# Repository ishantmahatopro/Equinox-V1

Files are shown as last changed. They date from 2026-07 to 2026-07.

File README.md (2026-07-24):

# Equinox V1

Equinox V1 is my custom full size (108 key) wireless mechanical keybaord, its built around a **Adafruit Feather nRF52840 Express**.

so basicaly i wanted a full size board that could go fully wireles over bluetooth but still work as a normal wired keyboard when i need it too, and i really didnt want to just buy some kit and screw it togther.. i wanted to actualy understand how the whole thing works like the matrix the diodes the I2C gpio expanders the battery the little screen ALL of it, so i designed the entire thing from scratch in kicad and fusion 360 which took forever lol

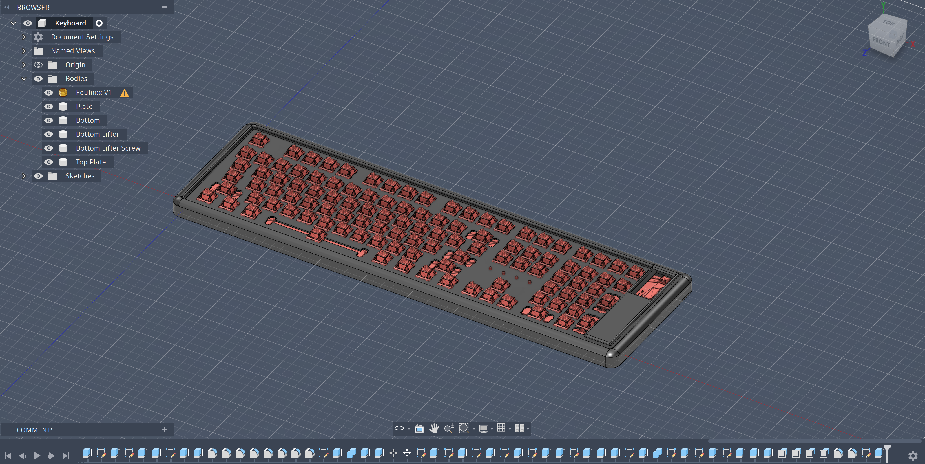
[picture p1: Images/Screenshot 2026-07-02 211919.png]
Equinox V1 full 3D model


## why i made this

im 17 and i basicaly live on my keyboard, school work,coding, everything.. so i figured if im gonna be typing on somthing like 8 hours a day it might aswell be somthing i built myself and actualy understand top to bottom right

main goals i set for myself :

- design a full size PCB in kicad (108 keys, numpad + nav cluster included)
- make it **wireless** (BLE) off a lipo battery,, but keep usb-c as a backup incase
- drive a huge key matrix off only 2 I2C pins using the MCP23017 expanders
- add a little 1.9" LCD that runs a animated cherry blossom scene, just becuase i thought it looked cool
- keep the whole thing actualy manufacturable (real production files not just a pretty render)
- learn the full pipline : schematic -> pcb -> 3d model -> printed case -> firmware

honestly the wireless part was the scaryest bit and it took me alot of trys to get the matrix scaning right over the expanders,, but it works now so im happy

## project status

this repo has the complete hardware design + manufacturing outputs. its basicaly done as a "V1", theres definately stuff i would change for a V2 but everything here is real and usable

whats included :

- kicad project, schematic and pcb
- full 3d cad (fusion 360 + `.step` export)
- printable case parts (`.stl`) and a plate dxf
- production files (bom, positions, designators, ipc netlist, gerber zip)
- kmk firmware for the nrf52840

current hardware summary :

| | |
|---|---|
| Layout | full size, 108 keys (main block + nav + numpad) |
| Controller | Adafruit Feather nRF52840 Express |
| Connectivity | bluetooth LE **and** usb-c (Fn+Esc toggles at runtime) |
| Matrix | 21 columns x 6 rows, scaned through 2x MCP23017 I2C expanders |
| Diodes | 1N4148W, one per switch (COL2ROW) |
| Battery | 500mAh 1S lipo, with charge / low battery status leds |
| Display | Waveshare 1.9" ST7789 IPS lcd (animated cherry blossom scene) |
| Stabilizers | Durock Clear screw-in V2 (6.25u space + 2u / 2.25u / 2.75u) |
| Switches | Akko V3 Penguin Pro |
| Keycaps | Plum Blossom cherry profile shine-through PBT |
| Case | 3d printed (Hack Club PrintLegion) |
| PCB | fabbed at JLCPCB |

the keycaps are pink plum blossom shine through and the lcd runs a pink cherry blossom animation so the whole "Equinox" theme kinda just came togther around that,, wasnt even fully planned tbh

## images

### full 3d model
Assembled 3D model with switches

### indicator leds (caps / num / charging)
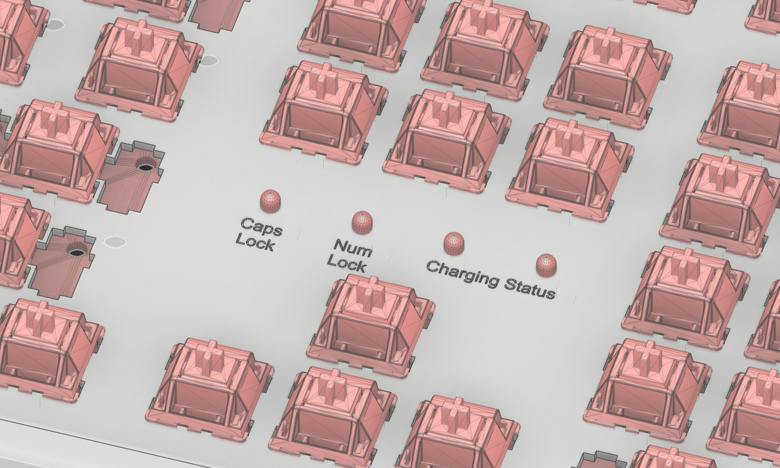
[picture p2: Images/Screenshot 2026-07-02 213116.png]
Close up of the status LED indicators


### pcb
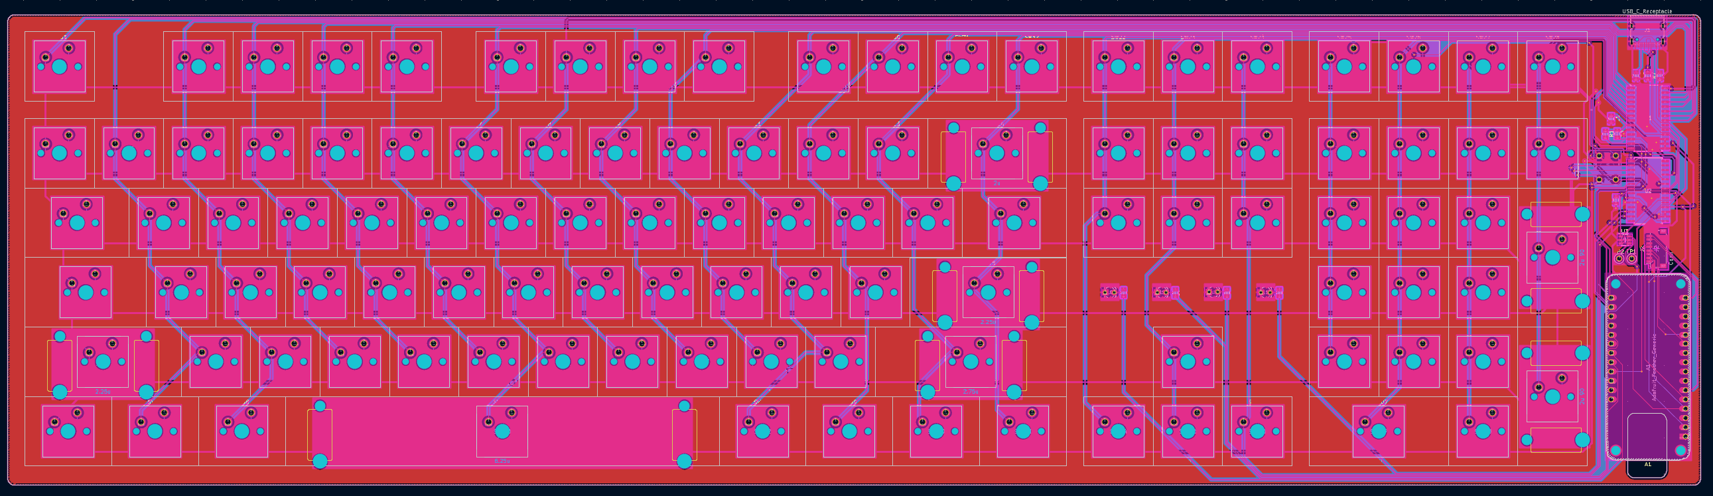
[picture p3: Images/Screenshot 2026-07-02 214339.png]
Equinox V1 PCB routing


### schematic / wiring
the matrix, both gpio expanders, the mcu, usb-c, esd protection, stabs and display are all on one sheet..

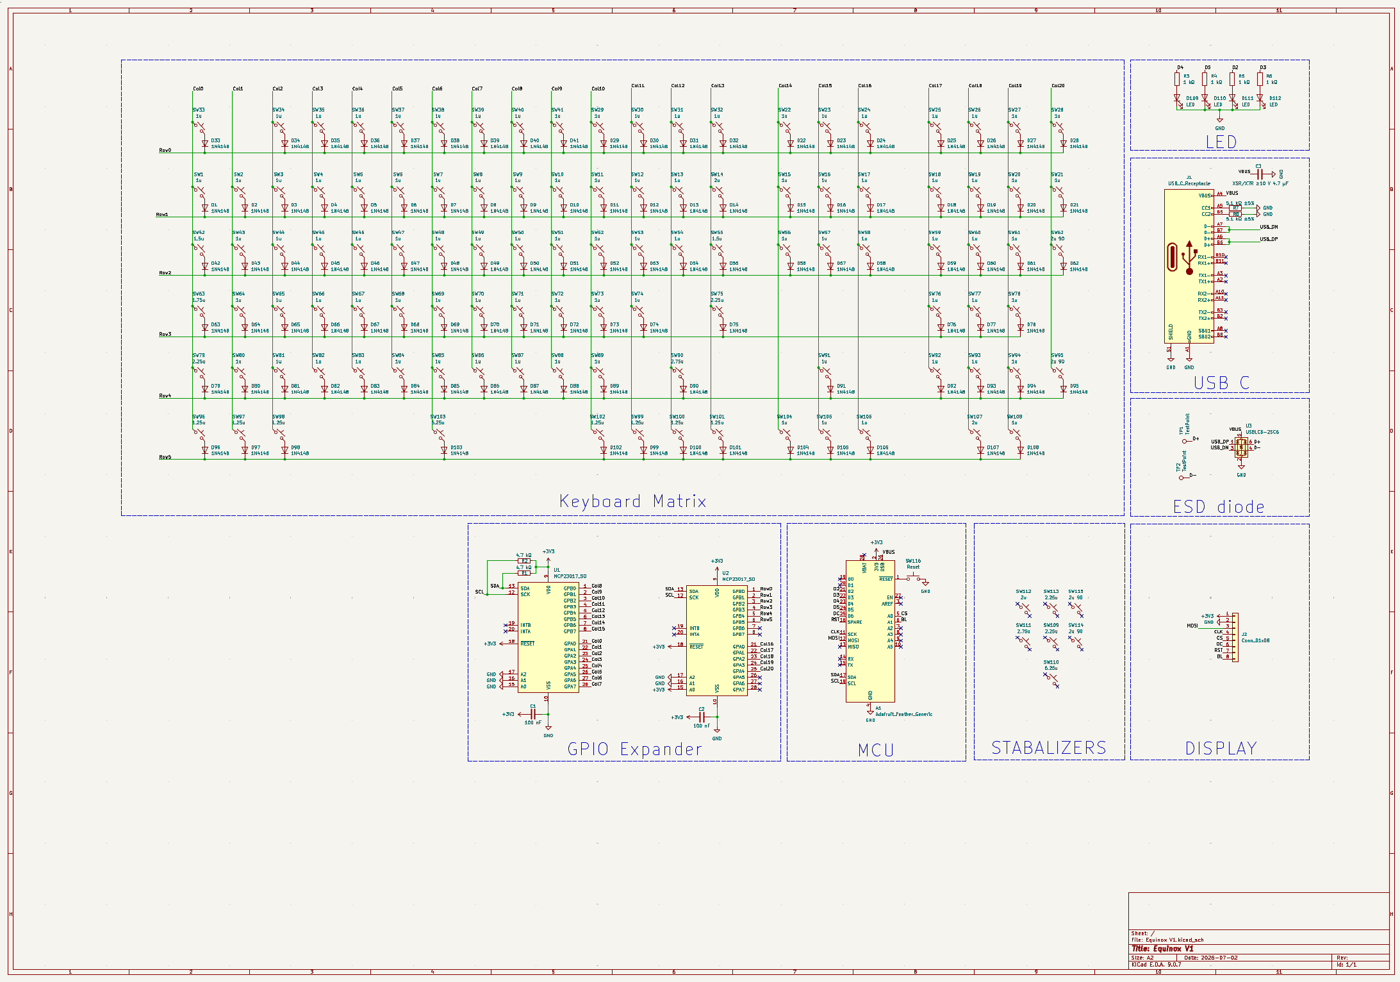
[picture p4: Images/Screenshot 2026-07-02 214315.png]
Equinox V1 schematic


### other screenshots
some more views of the case and plate from fusion

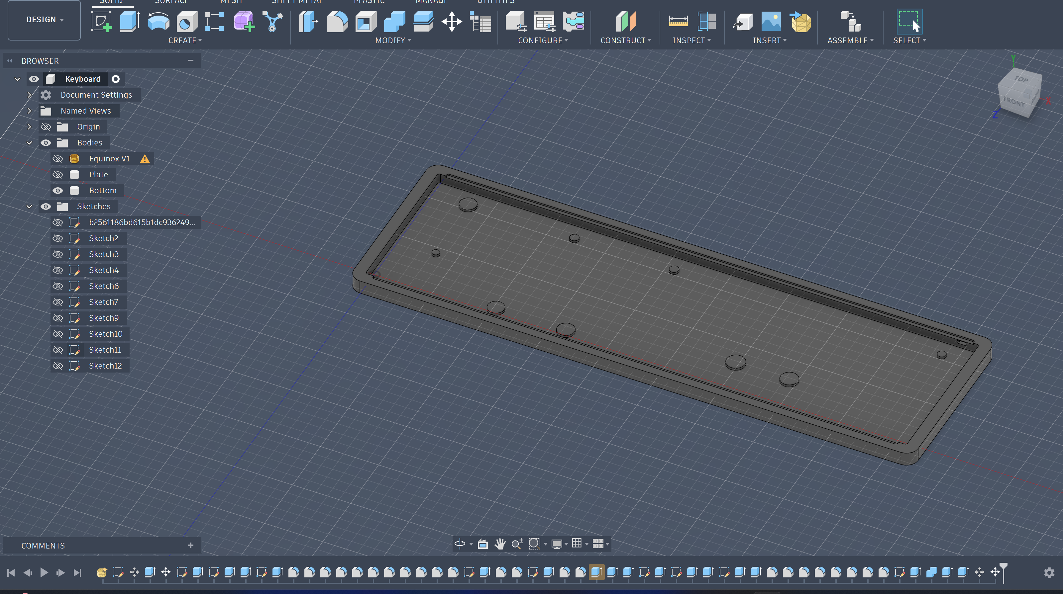
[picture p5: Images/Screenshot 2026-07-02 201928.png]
Case tray

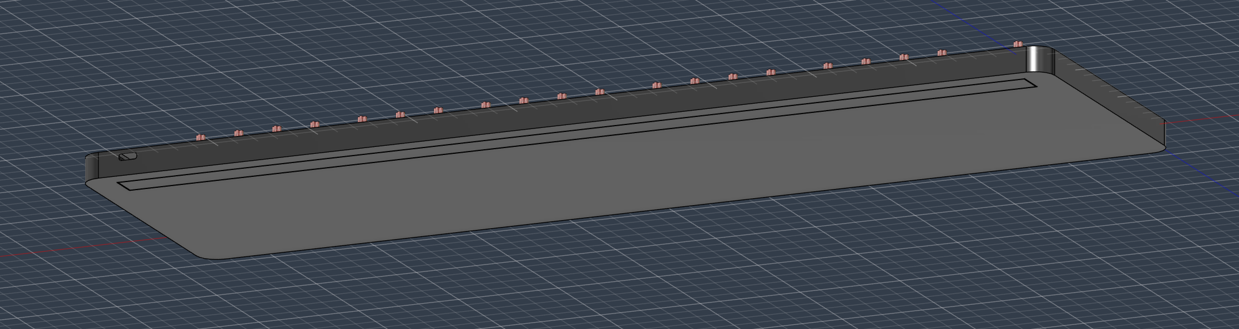
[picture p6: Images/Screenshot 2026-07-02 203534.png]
Case side profile

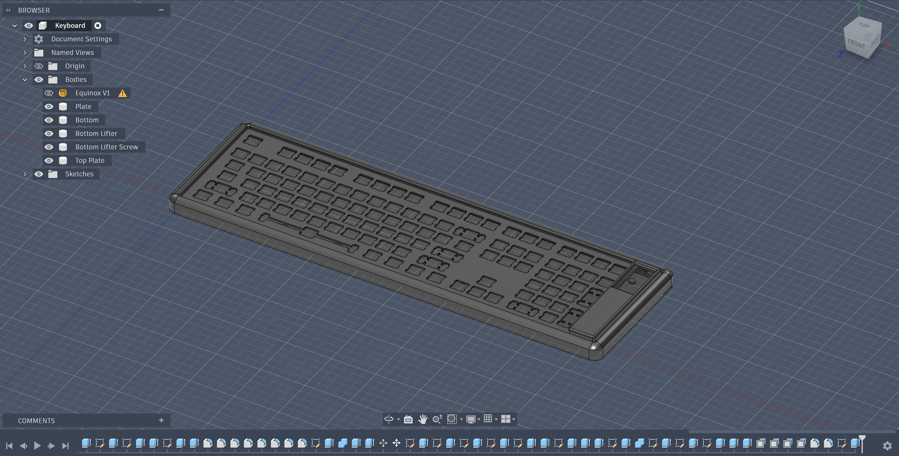
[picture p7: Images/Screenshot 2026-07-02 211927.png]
Switch plate cutouts

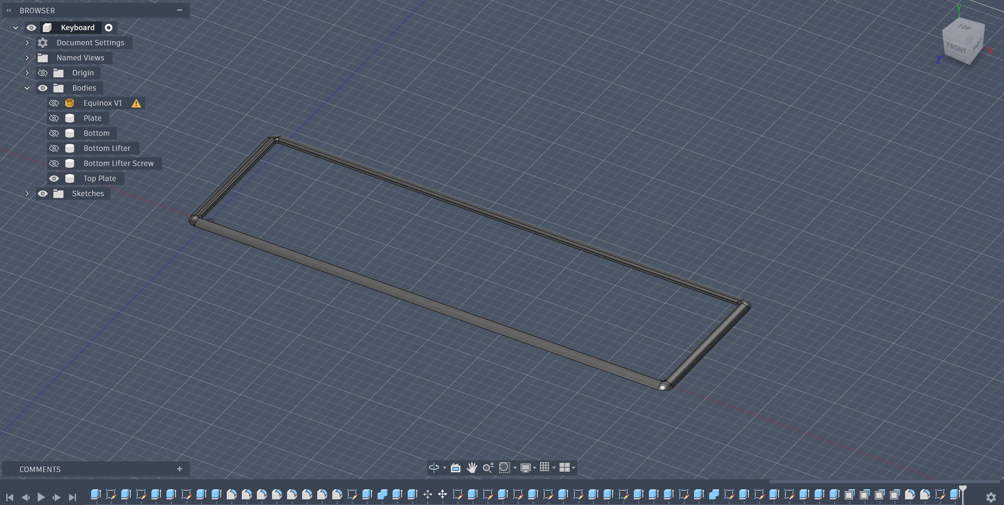
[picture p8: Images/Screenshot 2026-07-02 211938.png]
Top plate frame

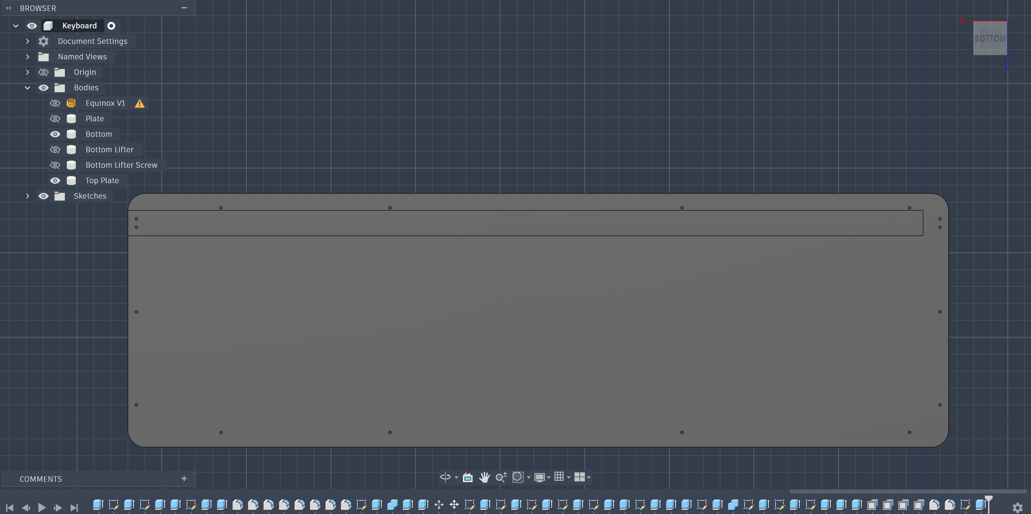
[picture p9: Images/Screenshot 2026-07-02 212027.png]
Bottom case


## repo file checklist

important files in this repo :

- `PCB/Equinox V1.kicad_pro`
- `PCB/Equinox V1.kicad_sch`
- `PCB/Equinox V1.kicad_pcb`
- `CAD/Full Equinox V1/Equinox V1.step`
- `CAD/Printing Files/`  -> `Plate.stl`, `Top Plate.stl`, `Bottom.stl`, `Bottom Lifter.stl`, `Bottom Lifter Screw.stl`
- `Firmware/code.py`
- `Production/bom.csv`
- `Production/positions.csv`
- `Production/designators.csv`
- `Production/netlist.ipc`
- `Production/Equinox_V1.zip`  (gerbers)
- `bom.csv`
- `PDFs/Equinox V1.pdf`  (schematic print)

## cad

designed in **fusion 360**.. theres a `.step` export right next to it if you just want the geometry. all the print ready parts are in `CAD/Printing Files/`

## firmware note

firmware is **KMK** running on **circuitpython**, its all in one file :

- `Firmware/code.py`

it has the real nrf52840 feather pin map, both MCP23017 adresses (`0x20` and `0x21`), the full 108 key layout maped from my layout photo, the lock/battery led logic and the cherry blossom lcd animation. all the periferal code is wraped in try/except so if a display or a led pin is wrong it still lets you type it just skips that part

to flash it : double tap RESET on the feather, drop the circuitpython `.uf2`, then copy `code.py` plus the `kmk/` folder and the required `lib/` drivers (`adafruit_mcp230xx`, `adafruit_bus_device`, `adafruit_ble`, `adafruit_st7789`, `adafruit_display_text`) onto the `CIRCUITPY` drive

by defalt it boots as **usb** (easyest for first bring up) and **Fn+Esc** switches over to bluetooth. if you want it wireless first just swap `hid_type` and `secondary_hid_type` at the bottom of `code.py`

## bom (summary)

full bom is in `bom.csv`. prices are what i actualy payed (usd)

| # | Name | Purpose | Qty | Cost ($) | Distributor | Link |
|---|---|---|-----|---|---|---|
| 1 | 3D printed Case | keyboard case | 1 | 8 | Hack Club | [Buy](https://printlegion.hackclub.com) |
| 2 | PCB fabrication | the main board | 1 | 39.36 | JLCPCB | [Buy](https://cart.jlcpcb.com/shopcart/cart) |
| 3 | Plum Blossom Cherry Profile Top Shine-Through PBT Keycap Set V2 | keycaps to actualy type on | 1 | 28.35 | Curiosity Caps | [Buy](https://curiositycaps.in/products/plum-blossom-cherry-profile-shine-through-dye-sublimation-pbt-keycap-set) |
| 4 | Durock Clear Screw-In Stabilizers V2 | stabalizers to keep the big keys stable | 1 | 24.83 | Stackskb | [Buy](https://stackskb.com/store/durock-clear-screw-in-stabilizers-v2/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) |
| 5 | Akko V3 Penguin Pro Switch (Pack of 45) | switches for the keys | 3(Already Have) | 47.22 | Stackskb | [Buy](https://stackskb.com/store/akko-penguin-pro-switch-pack-of-45/) |
| 6 | Adafruit Feather nRF52840 Express | microcontroler / the brains | 1 | 32.02 | Robu | [Buy](https://robu.in/product/adafruit-feather-nrf52840-express/) |
| 7 | WLY752530 3.7V 500mAh 1S LiPo Battery | battery | 1 | 2.74 | Robu | [Buy](https://robu.in/product/500mah-pcm-protected-micro-li-po-battery/) |
| 8 | 0805 X7R 100nF 50V ceramic capacitors | capacitors | 10 | 0.12 | Robu | [Buy](https://robu.in/product/tcc0805x7r104j500dt-cctc-smt-ceramic-capacitors-0805-x7r-104j100nf%c2%b15-0-rated-voltage50v-thickness0-85mmtape/) |
| 9 | Samsung 4.7uF 10V X7R 0805 capacitors | capacitors | 5 | 0.12 | Robu | [Buy](https://robu.in/product/cl21b475kpqvpne-samsung-cap-ceramic-4-7uf-10v-x7r-10-pad-smd-0805-125c-t-r-automotive-aec-q200/) |
| 10 | 1N4148W SOD-123 Diode | diode (1 per switch) | 216 | 1.59 | Robu | [Buy](https://robu.in/product/1n4148w-sod-123-1206-diodereel-of-3000/) |
| 11 | 3mm Green DIP LED | led | 15 | 0.12 | Robu | [Buy](https://robu.in/product/3mm-green-dip-led-pack-of-50/) |
| 12 | 3mm Red DIP LED | led | 15 | 0.14 | Robu | [Buy](https://robu.in/product/3mm-red-dip-led-pack-of-50/) |
| 13 | 16P Female Type-C SMD Connector | usb-c port | 2 | 0.8 | Robu | [Buy](https://robu.in/product/type-c-31-m-12-hroparts-5a-1-16p-female-type-c-smd-usb-connectors-rohs/) |
| 14 | XY308-2.54 3 Pin Screw Terminal Block | battery terminal | — | Free | Robu | — |
| 15 | JST SH 1x8P Right Angle Connector | display conection | 2 | 1.09 | Robu | [Buy](https://robu.in/product/sm08b-srss-tblfsn-jst-1x8p-8p-sh-tin-8-25%e2%84%8385%e2%84%83-1a-1-1mm-copper-alloy-surface-mount-smdp1mmsurface-mount%ef%bc%8cright-angle-wi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) |
| 16 | Panasonic 4.7 kohm 0805 resistor | resistors (i2c pullups) | 11 | 0.11 | Robu | [Buy](https://robu.in/product/erj6enf4701v-panasonic-smd-chip-resistor-4-7-kohm-%c2%b1-1-125-mw-0805-2012-metric-thick-film-precision/) |
| 17 | Vishay 1 kohm 0805 resistor | resistors (led current limit) | 20 | 0.72 | Robu | [Buy](https://robu.in/product/crcw08051k00fkeahp-vishay-smd-chip-resistor-1-kohm-%c2%b1-1-500-mw-0805-2012-metric-thick-film-pulse-proof-high-power/) |
| 18 | Yageo 5.1 kohm 0805 resistor | resistors | 100 | 0.14 | Robu | [Buy](https://robu.in/product/rc0805jr-075k1l-yageo-smd-chip-resistor-5-1-kohm-%c2%b1-5-125-mw-0805-2012-metric-thick-film-general-purpose/) |
| 19 | MCP23017-E/SO I/O Expander (16-bit, I2C) | gpio expander | 4 | 8.78 | Robu | [Buy](https://robu.in/product/mcp23017-e-so-microchip-i-o-expander-16-bit-i2c-serial-1-8-v-5-5-v-soic-28-pins/) |
| 20 | USBLC6-2SC6 SOT-23-6 | esd / surge protection | 5 | 0.37 | Robu | [Buy](https://robu.in/product/usblc6-2sc6-ms-msksemi-4-5a-15v-150w-6v-5v-sot-23-6-esd-and-surge-protection-tvs-esd-rohs/) |
| 21 | Waveshare 1.9inch LCD Display Module (SPI, IPS) | the screen | 1 | 11.17 | Robu | [Buy](https://robu.in/product/waveshare-lcd-display-module-spi-interface-262k-colors/) |

**total bom cost : $160**

---

thanks for reading,, if you build one or have any questions feel free to open a issue. this was my first proper wireless board so its deffinately not perfect but i learnt a insane amount making it :)

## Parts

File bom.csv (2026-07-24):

Name | Purpose | Quantity | Total Cost ($) | Link | Distributor
3D printed Case | Keyboard Case | 1 | 8 | https://printlegion.hackclub.com | Hack Club
PCB fabrication | Keyboard Main Board | 1 | 39.36 | https://cart.jlcpcb.com/shopcart/cart | JLCPCB
Plum Blossom Cherry Profile Top Shine-Through PBT Keycap Set V2 | KeyCaps for the Keyboard to type | 1 | 28.35 | https://curiositycaps.in/products/plum-blossom-cherry-profile-shine-through-dye-sublimation-pbt-keycap-set | Curiosity Caps
Durock Clear Screw-In Stabilizers V2 | Stabalizers to keep Big keys stable | 1 | 24.83 | https://stackskb.com/store/durock-clear-screw-in-stabilizers-v2/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 | Stackskb
Akko V3 Penguin Pro Switch (Pack of 45) | Switches for the Keys | 3 | 47.22 | https://stackskb.com/store/akko-penguin-pro-switch-pack-of-45/ | Stackskb
Adafruit Feather nRF52840 Express | Microcontroller | 1 | 32.02 | https://robu.in/product/adafruit-feather-nrf52840-express/ | Robu
WLY752530 3.7V 500mAh 1S LiPo Battery – Micro Rechargeable Battery Pack for Wearables / Micro Drone / IoT | Battery | 1 | 2.74 | https://robu.in/product/500mah-pcm-protected-micro-li-po-battery/ | Robu
TCC0805X7R104J500DT-CCTC-SMT ceramic capacitors 0805 X7R 104J(100nF)±5.0% Rated voltage:50V thickness:0.85mmtape | Capacitors | 10 | 0.12 | https://robu.in/product/tcc0805x7r104j500dt-cctc-smt-ceramic-capacitors-0805-x7r-104j100nf%c2%b15-0-rated-voltage50v-thickness0-85mmtape/ | Robu
CL21B475KPQVPNE-Samsung-Cap Ceramic 4.7uF 10V X7R 10% Pad SMD 0805 125°C T/R Automotive AEC-Q200 | Capacitors | 5 | 0.12 | https://robu.in/product/cl21b475kpqvpne-samsung-cap-ceramic-4-7uf-10v-x7r-10-pad-smd-0805-125c-t-r-automotive-aec-q200/ | Robu
1N4148W SOD-123 1206 Diode | Diode | 216 | 1.59 | https://robu.in/product/1n4148w-sod-123-1206-diodereel-of-3000/ | Robu
3mm Green DIP LED | Led | 15 | 0.12 | https://robu.in/product/3mm-green-dip-led-pack-of-50/ | Robu
3mm Red DIP LED | Led | 15 | 0.14 | https://robu.in/product/3mm-red-dip-led-pack-of-50/ | Robu
TYPE-C-31-M-12-Hroparts-5A 1 16P Female Type-C SMD USB Connectors ROHS | Type C | 2 | 0.8 | https://robu.in/product/type-c-31-m-12-hroparts-5a-1-16p-female-type-c-smd-usb-connectors-rohs/ | Robu
XY308-2.54-XINYA-3 Pin Screw Terminal Block(Red) | Free |  |  |  | Robu
SM08B-SRSS-TB(LF)(SN)-JST-1x8P 8P SH Tin 8 -25?~+85? 1A 1 1mm Copper alloy Surface Mount SMD,P=1mm,Surface Mount?Right Angle Wire To Board Connector ROHS | OLED Connection | 2 | 1.09 | https://robu.in/product/sm08b-srss-tblfsn-jst-1x8p-8p-sh-tin-8-25%e2%84%8385%e2%84%83-1a-1-1mm-copper-alloy-surface-mount-smdp1mmsurface-mount%ef%bc%8cright-a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 | Robu
ERJ6ENF4701V-PANASONIC-SMD Chip Resistor, 4.7 kohm, ± 1%, 125 mW, 0805 [2012 Metric], Thick Film, Precision | Resistors | 11 | 0.11 | https://robu.in/product/erj6enf4701v-panasonic-smd-chip-resistor-4-7-kohm-%c2%b1-1-125-mw-0805-2012-metric-thick-film-precision/ | Robu
CRCW08051K00FKEAHP-VISHAY-SMD Chip Resistor, 1 kohm, ± 1%, 500 mW, 0805 [2012 Metric], Thick Film, Pulse Proof, High Power | Resistors | 20 | 0.72 | https://robu.in/product/crcw08051k00fkeahp-vishay-smd-chip-resistor-1-kohm-%c2%b1-1-500-mw-0805-2012-metric-thick-film-pulse-proof-high-power/ | Robu
RC0805JR-075K1L-Yageo-SMD Chip Resistor, 5.1 kohm, ± 5%, 125 mW, 0805 [2012 Metric], Thick Film, General Purpose | Resistors | 100 | 0.14 | https://robu.in/product/rc0805jr-075k1l-yageo-smd-chip-resistor-5-1-kohm-%c2%b1-5-125-mw-0805-2012-metric-thick-film-general-purpose/ | Robu
MCP23017-E/SO MICROCHIP I/O Expander, 16 bit, I2C, Serial, 1.8 V, 5.5 V, SOIC, 28 Pins | GPIO Expander | 4 | 8.78 | https://robu.in/product/mcp23017-e-so-microchip-i-o-expander-16-bit-i2c-serial-1-8-v-5-5-v-soic-28-pins/ | Robu
USBLC6-2SC6-MS-MSKSEMI-4.5A 15V 150W 6V 5V SOT-23-6 ESD and Surge Protection (TVS/ESD) ROHS |  | 5 | 0.37 | https://robu.in/product/usblc6-2sc6-ms-msksemi-4-5a-15v-150w-6v-5v-sot-23-6-esd-and-surge-protection-tvs-esd-rohs/ | Robu
Waveshare 1.9inch LCD Display Module, SPI Interface, IPS, 262K Colors | OLED Screen | 1 | 11.17 | https://robu.in/product/waveshare-lcd-display-module-spi-interface-262k-colors/ | Robu
Total |  |  | 207.79$

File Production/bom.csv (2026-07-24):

Designator | Footprint | Quantity | Value | LCSC Part #
A1 | Adafruit_Feather_WithMountingHoles | 1 | Adafruit_Feather_Generic
C1, C2 | 0805 | 2 | 100 nF
C3 | 0805 | 1 | X5R/X7R ≥10 V 4.7 µF
D1, D10, D100, D101, D102, D103, D104, D105, D106, D107, D108, D11, D12, D13, D14, D15, D16, D17, D18, D19, D2, D20, D21, D22, D23, D24, D25, D26, D27, D28, D29, D3, D30, D31, D32, D33, D34, D35, D36, D37, D38, D39, D4, D40, D41, D42, D43, D44, D45, D46, D47, D48, D49, D5, D50, D51, D52, D53, D54, D55, D56, D57, D58, D59, D6, D60, D61, D62, D63, D64, D65, D66, D67, D68, D69, D7, D70, D71, D72, D73, D74, D75, D76, D77, D78, D79, D8, D80, D81, D82, D83, D84, D85, D86, D87, D88, D89, D9, D90, D91, D92, D93, D94, D95, D96, D97, D98, D99 | D_SOD-123 | 108 | 1N4148
D109, D110, D111, D112 | LED_D3.0mm | 4 | LED
J1 | USB_C_Receptacle_HRO_TYPE-C-31-M-12 | 1 | USB_C_Receptacle
J2 | JST_SH_SM08B-SRSS-TB_1x08-1MP_P1.00mm_Horizontal | 1 | Conn_01x08
R1, R2 | 0805 | 2 | 4.7 kΩ
R3, R4, R5, R6 | 0805 | 4 | 1 kΩ
R7, R8 | 0805 | 2 | 5.1 kΩ ±5%
SW1, SW10, SW104, SW105, SW106, SW108, SW11, SW12, SW13, SW15, SW16, SW17, SW18, SW19, SW2, SW20, SW21, SW22, SW23, SW24, SW25, SW26, SW27, SW28, SW29, SW3, SW30, SW31, SW32, SW33, SW34, SW35, SW36, SW37, SW38, SW39, SW4, SW40, SW41, SW43, SW44, SW45, SW46, SW47, SW48, SW49, SW5, SW50, SW51, SW52, SW53, SW54, SW56, SW57, SW58, SW59, SW6, SW60, SW61, SW64, SW65, SW66, SW67, SW68, SW69, SW7, SW70, SW71, SW72, SW73, SW74, SW76, SW77, SW78, SW8, SW80, SW81, SW82, SW83, SW84, SW85, SW86, SW87, SW88, SW89, SW9, SW91, SW92, SW93, SW94 | SW_Cherry_MX_PCB_1.00u | 90 | 1u
SW100, SW101, SW102, SW96, SW97, SW98, SW99 | SW_Cherry_MX_PCB_1.25u | 7 | 1.25u
SW103 | SW_Cherry_MX_Plate_6.25u | 1 | 6.25u
SW107, SW14 | SW_Cherry_MX_PCB_2.00u | 2 | 2u
SW109, SW113 | STAB_MX_2.25u | 2 | 2.25u
SW110 | STAB_MX_6.25u | 1 | 6.25u
SW111 | STAB_MX_2.75u | 1 | 2.75u
SW112 | STAB_MX_2u | 1 | 2u
SW114, SW115 | STAB_MX_2u | 2 | 2u 90
SW116 | SW_PUSH_6mm | 1 | Reset
SW42, SW55 | SW_Cherry_MX_PCB_1.50u | 2 | 1.5u
SW62, SW95 | SW_Cherry_MX_PCB_2.00u_90deg | 2 | 2u 90
SW63 | SW_Cherry_MX_PCB_1.75u | 1 | 1.75u
SW75, SW79 | SW_Cherry_MX_PCB_2.25u | 2 | 2.25u
SW90 | SW_Cherry_MX_PCB_2.75u | 1 | 2.75u
TP1, TP2 | TestPoint_THTPad_D2.0mm_Drill1.0mm | 2 | TestPoint
U1, U2 | SOIC-28W_7.5x17.9mm_P1.27mm | 2 | MCP23017_SO
U3 | SOT-23-6 | 1 | USBLC6-2SC6

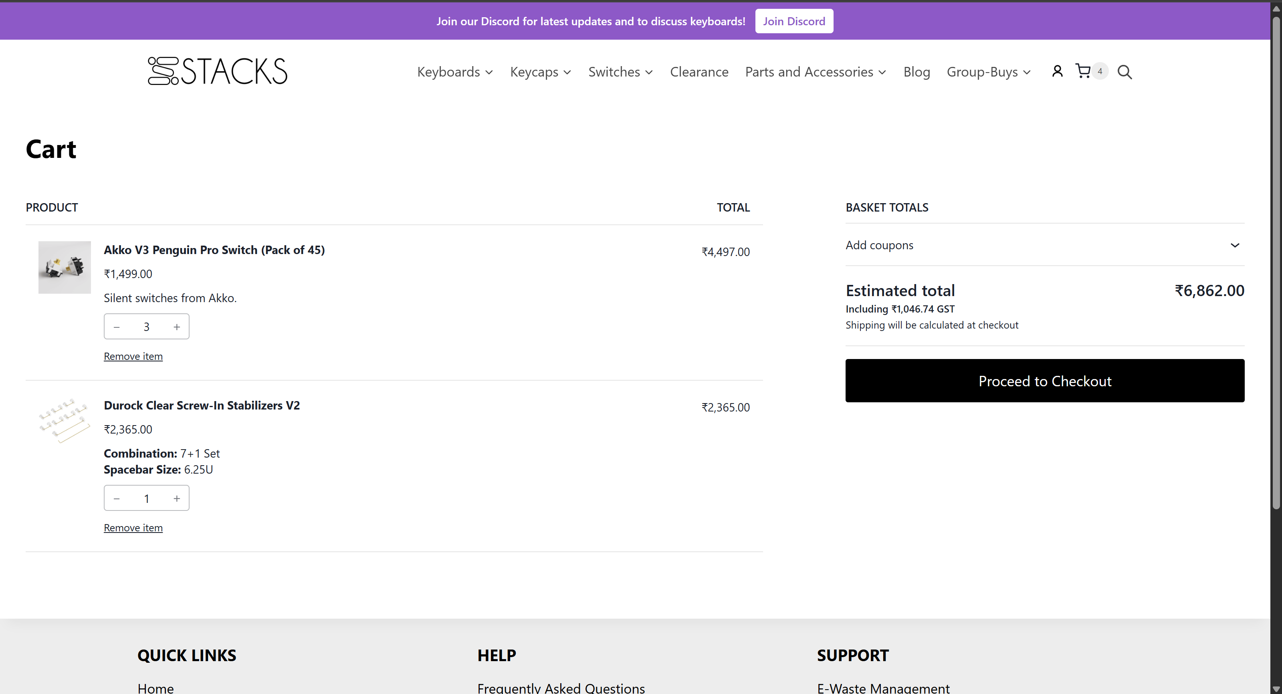
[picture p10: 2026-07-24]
BOM Images/Screenshot 2026-07-02 215916.png

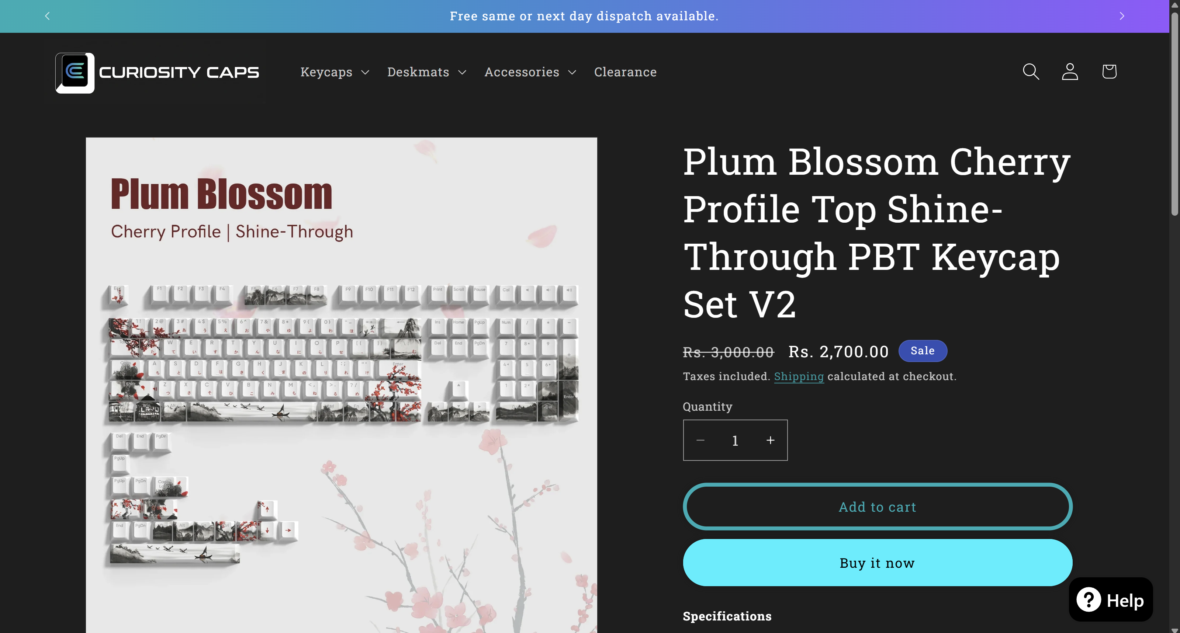
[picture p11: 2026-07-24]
BOM Images/Screenshot 2026-07-02 215601.png

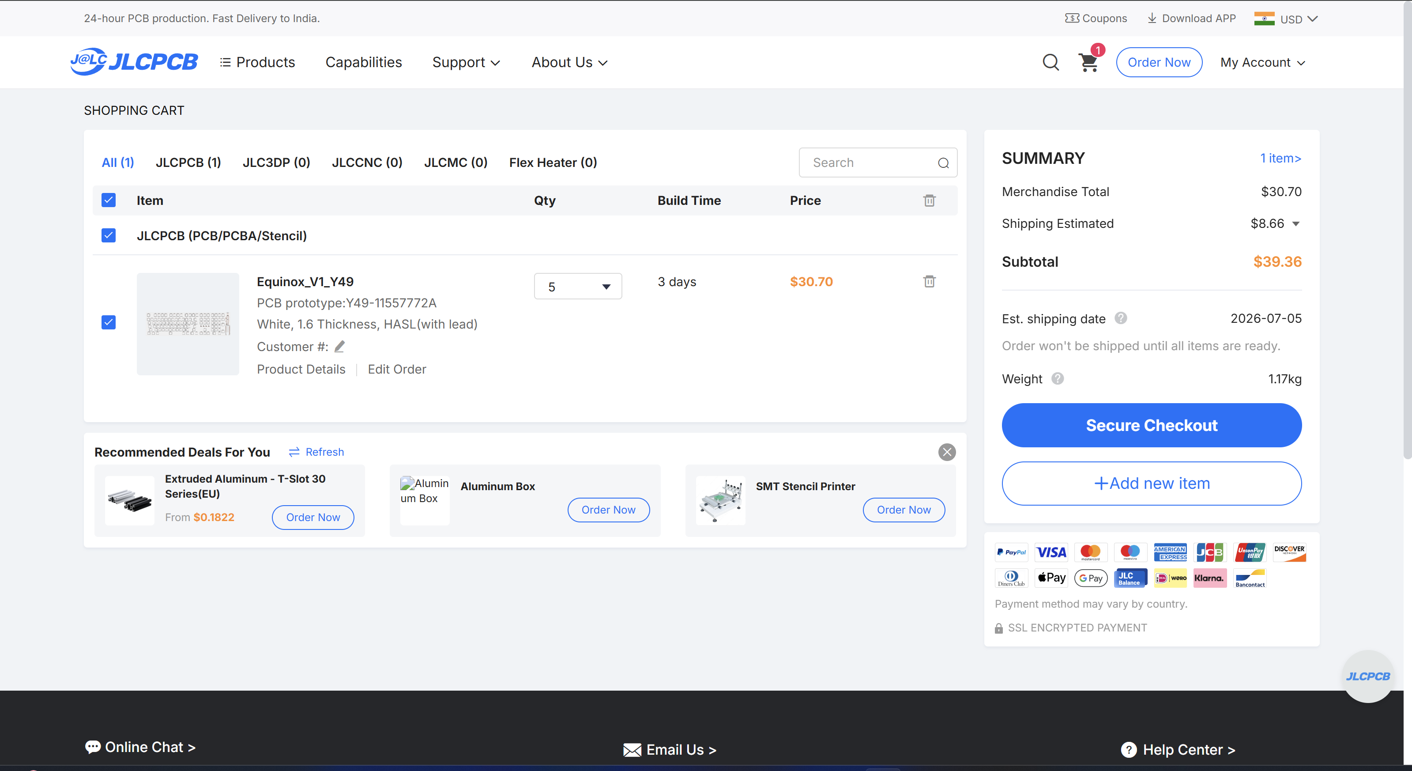
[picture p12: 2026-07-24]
BOM Images/Screenshot 2026-07-02 215439.png

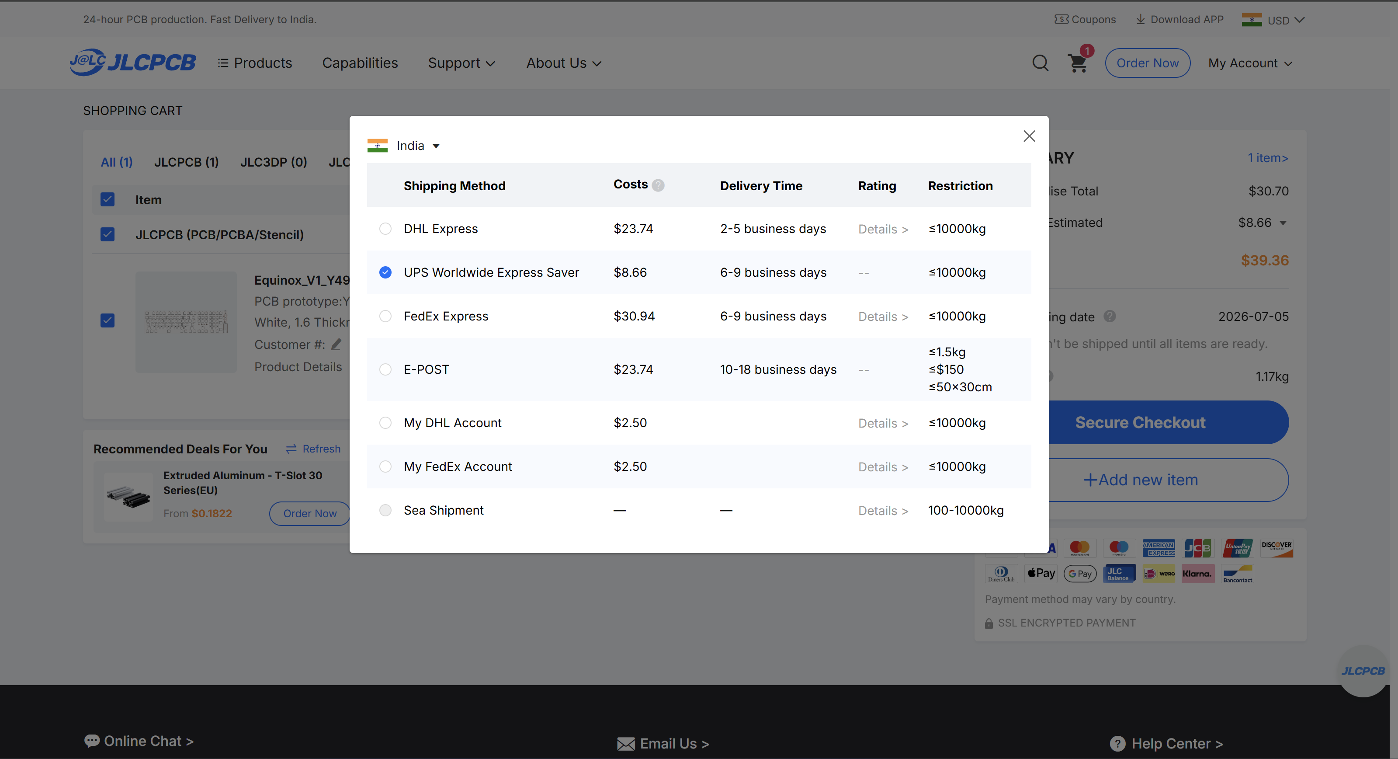
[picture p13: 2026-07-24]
BOM Images/Screenshot 2026-07-02 215447.png

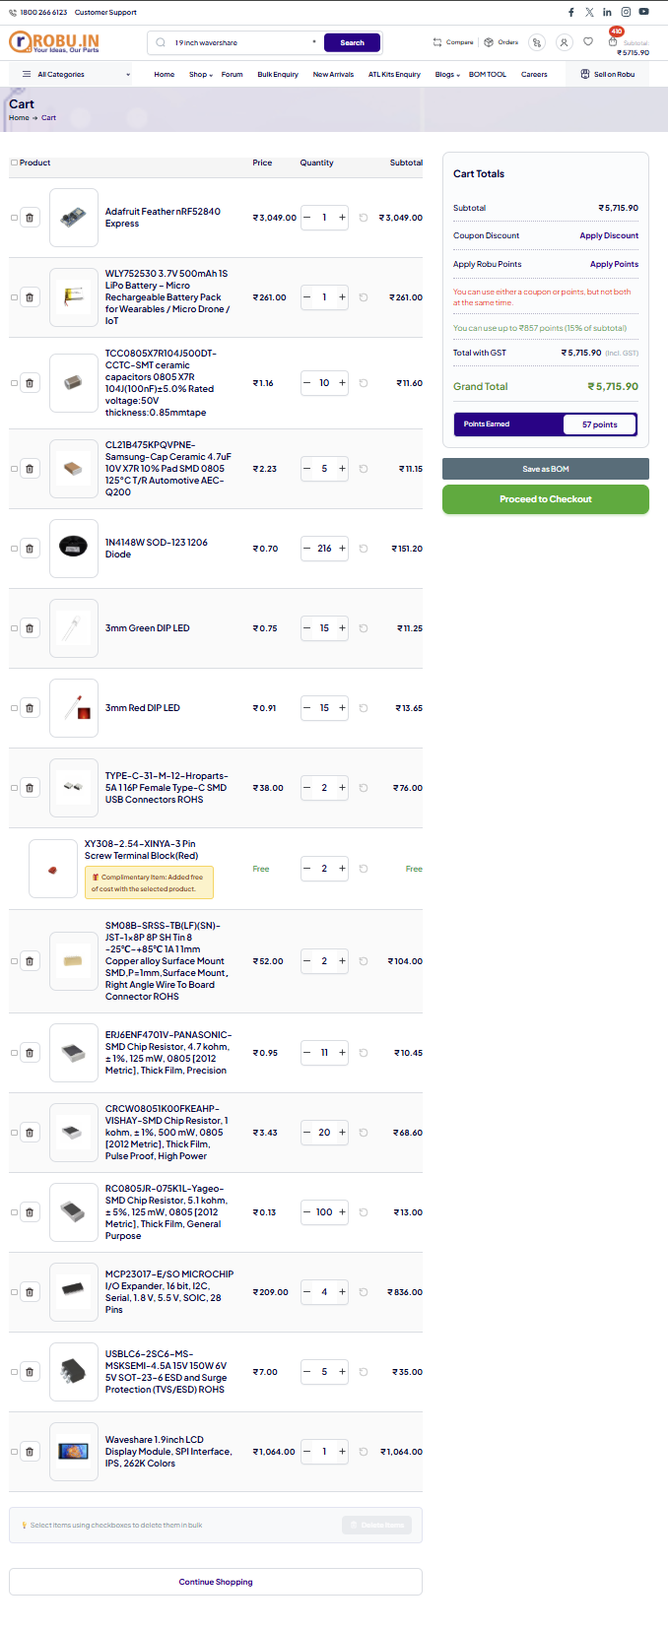
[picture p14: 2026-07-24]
BOM Images/Screenshot 2026-07-02 224403.png

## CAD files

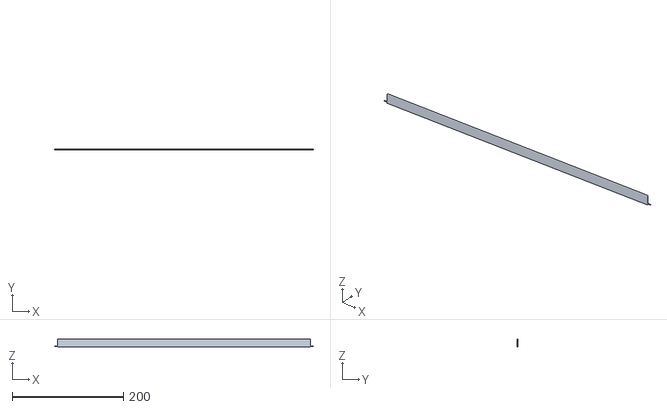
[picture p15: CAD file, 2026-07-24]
CAD/Printing Files/Bottom Lifter.stl
465.0 x 2.00 x 14.0

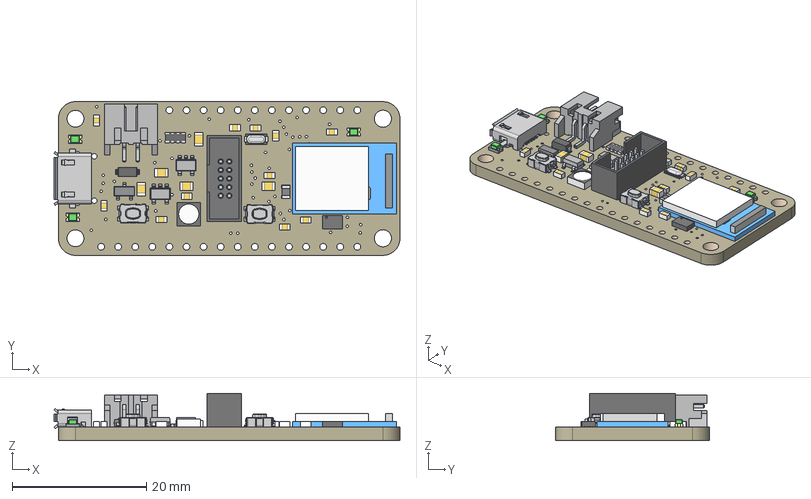
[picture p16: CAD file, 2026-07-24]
PCB/nRF52830/4062-nRF52830-Feather.step
51.5 x 22.9 x 6.99 mm
Board
2x5 0.05"
KMR2 x 2
AP2112(3.3V) x 2
BLUE x 3
JSTPH
4u20329
MBR120
DMG2305
MDBT50
GD25Q16
WS2812B3535
0.1uF x 11
10uF x 5
DNP
100K

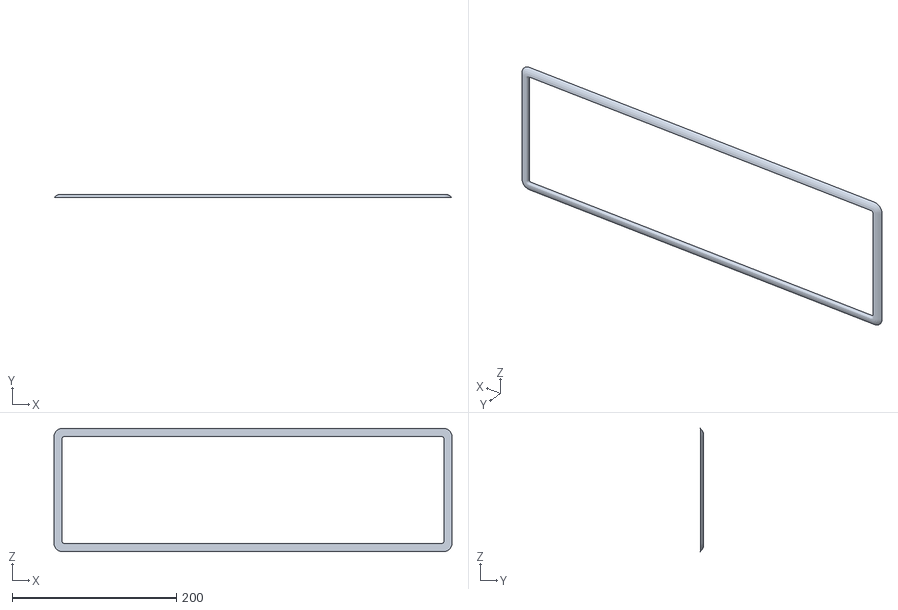
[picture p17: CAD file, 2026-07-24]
CAD/Printing Files/Top Plate.stl
485.0 x 4.00 x 150.0

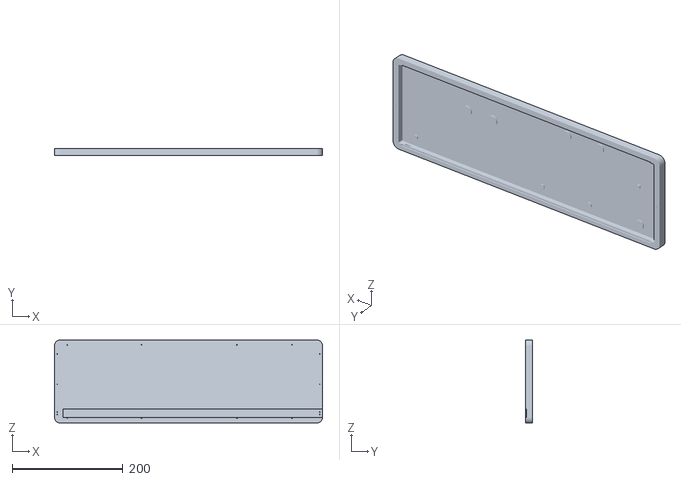
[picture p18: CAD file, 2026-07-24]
CAD/Printing Files/Bottom.stl
485.0 x 12.4 x 150.0

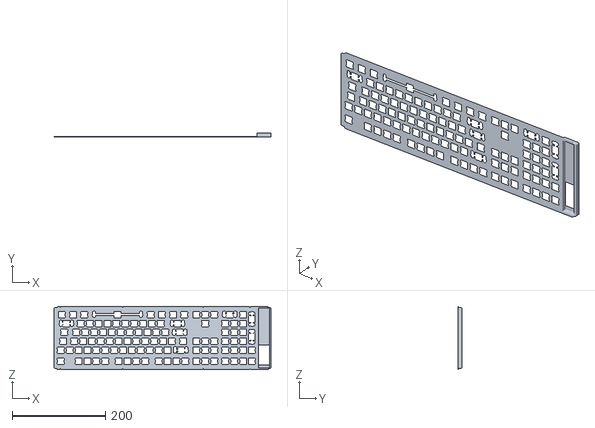
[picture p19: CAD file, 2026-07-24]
CAD/Printing Files/Plate.stl
465.0 x 9.50 x 136.0

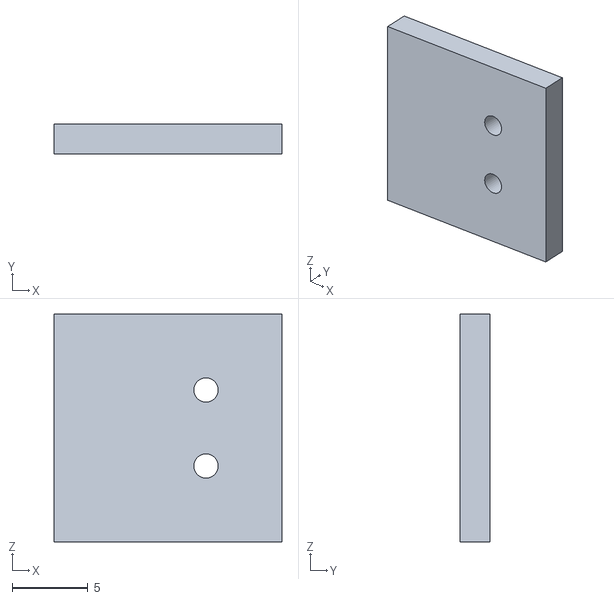
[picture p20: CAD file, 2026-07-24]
CAD/Printing Files/Bottom Lifter Screw.stl
15.0 x 2.00 x 15.0

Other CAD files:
FusionFiles/Equinox V1.f3d

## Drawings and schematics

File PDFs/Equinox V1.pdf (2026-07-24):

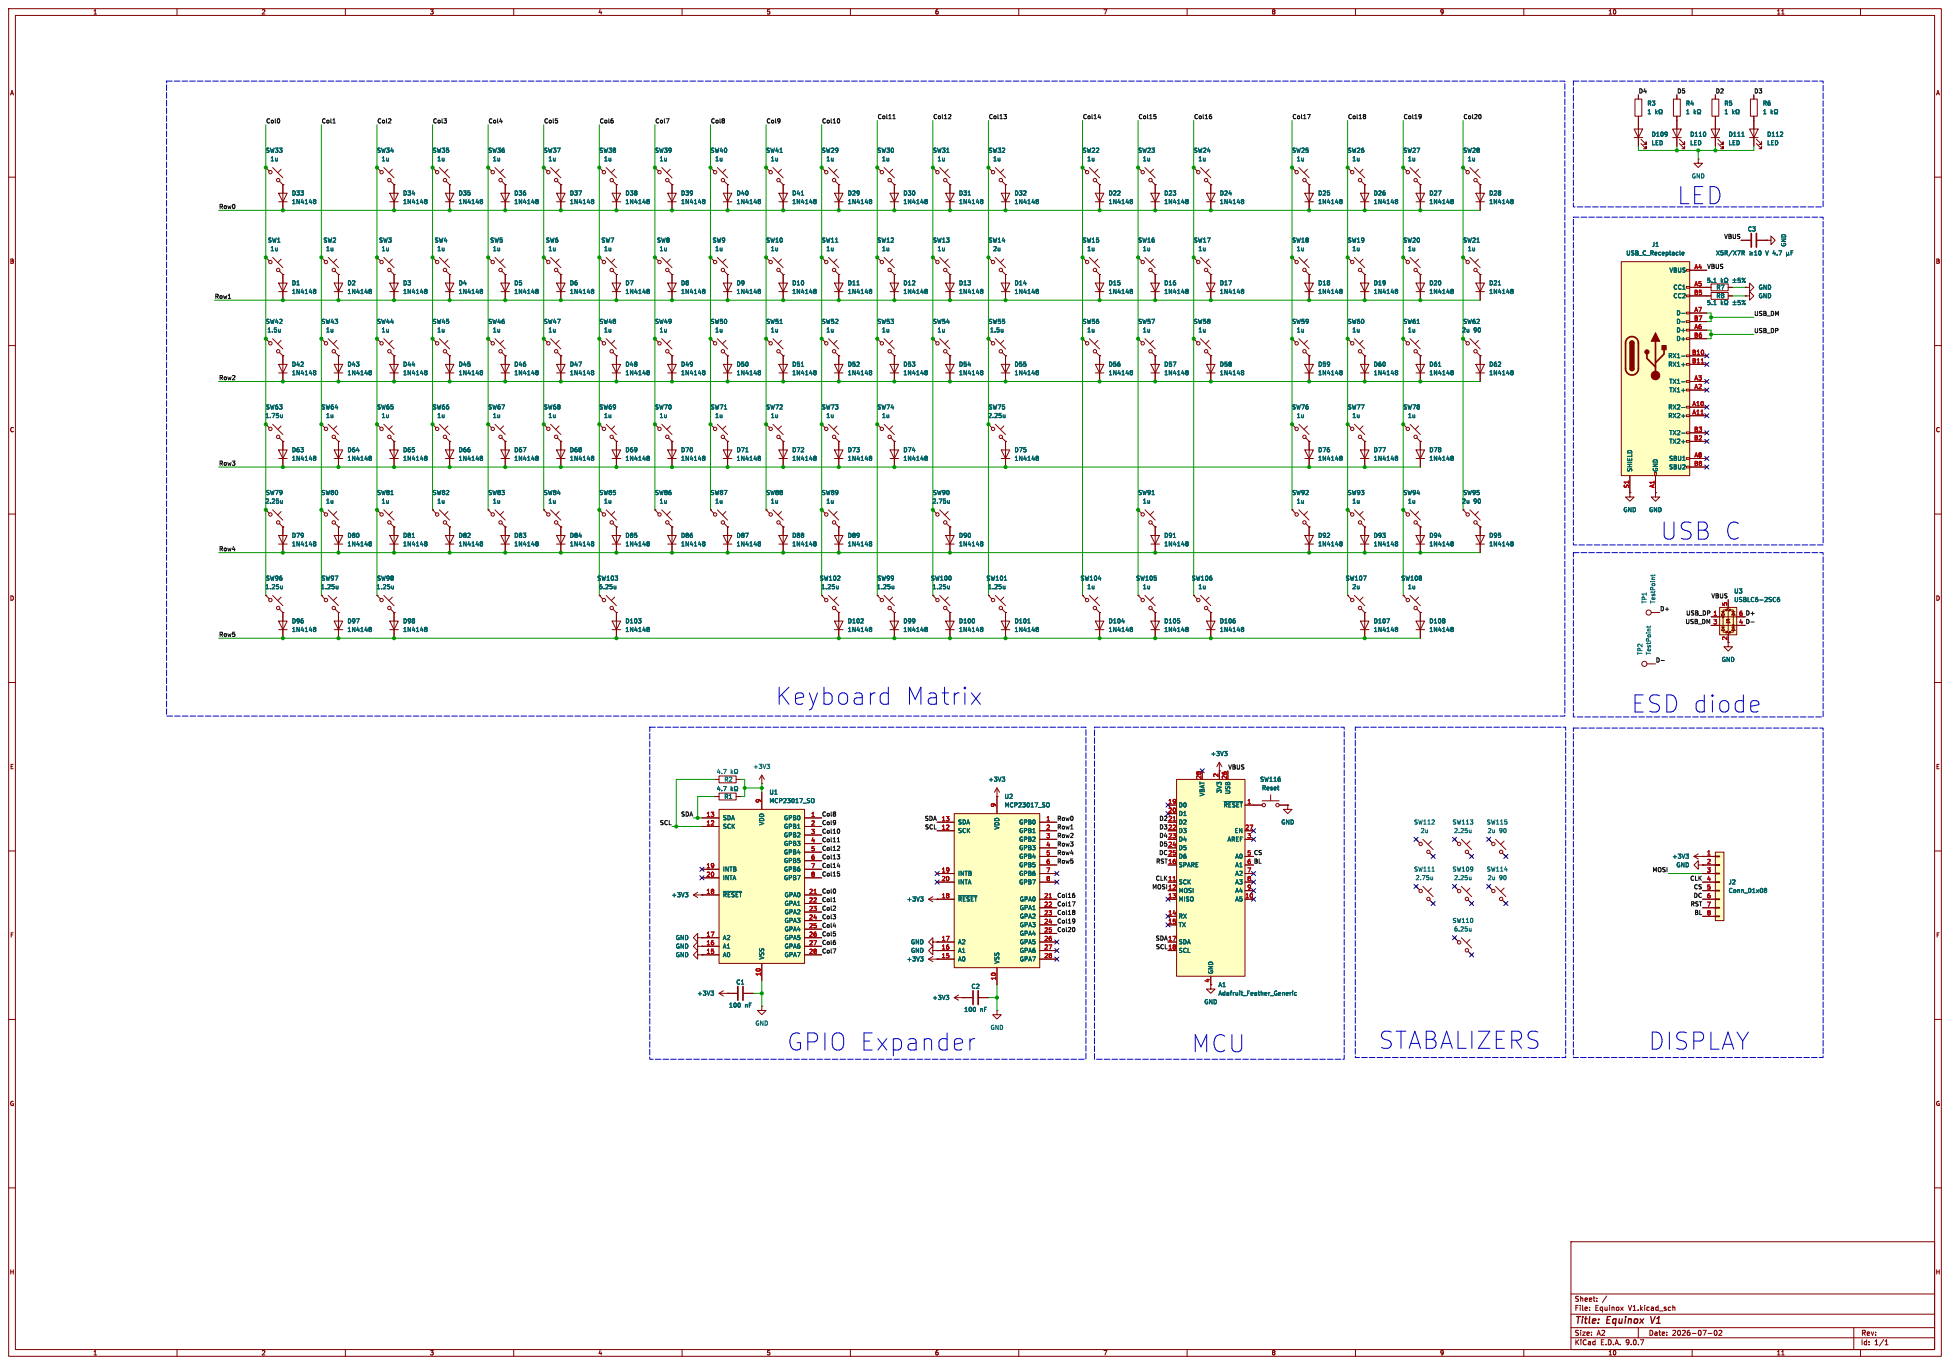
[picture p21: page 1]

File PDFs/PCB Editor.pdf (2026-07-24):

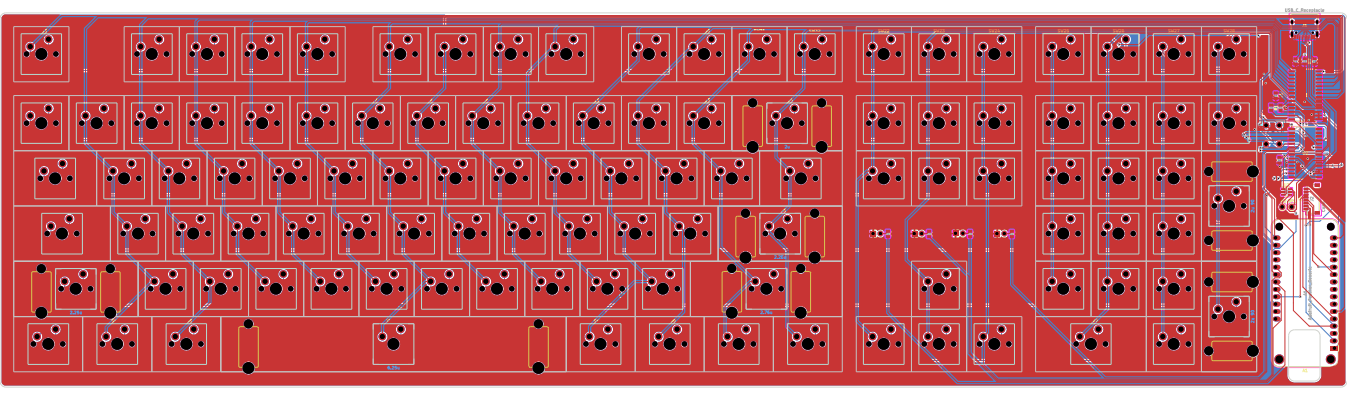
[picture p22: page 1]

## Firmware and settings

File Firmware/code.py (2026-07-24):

# =====================================================================
#  code.py  -  KMK firmware : full-size (108-key) wireless/wired keyboard
#
#  Board : Adafruit Feather nRF52840 Express  (CircuitPython)
#  Matrix: 2x MCP23017 I2C expanders
#            U1 @ 0x20  ->  Col0 .. Col15
#            U2 @ 0x21  ->  Col16 .. Col20  +  Row0 .. Row5
#  Layout: standard full-size, columns = 14 main + 3 nav + 4 numpad = 21
#  Diodes: COL2ROW
#  Extras: Caps/Num LEDs, battery LEDs, animated cherry-blossom LCD
#  Link  : USB + BLE  (Fn+Esc toggles between them at runtime)
# =====================================================================
#
#  COPY ONTO CIRCUITPY:
#    /code.py                      <- this file
#    /kmk/                         <- the 'kmk' folder from the KMK repo
#    /lib/adafruit_mcp230xx/       <- MCP23017 driver
#    /lib/adafruit_bus_device/     <- dependency of the MCP driver
#    /lib/adafruit_ble/            <- required for Bluetooth HID
#    /lib/adafruit_st7789.mpy      <- LCD driver   (optional: display)
#    /lib/adafruit_display_text/   <- status text  (optional: display)
#    (vectorio + random are built into CircuitPython)
#
#  FLASH: double-tap RESET -> FTHR840BOOT appears -> drop the CP .uf2 ->
#         CIRCUITPY appears -> copy this file + the folders above.
# =====================================================================

import board
import busio
import digitalio
import analogio

from kmk.kmk_keyboard import KMKKeyboard
from kmk.keys import KC
from kmk.scanners import DiodeOrientation
from kmk.scanners.digitalio import MatrixScanner
from kmk.hid import HIDModes
from kmk.modules.layers import Layers
from kmk.modules import Module

from adafruit_mcp230xx.mcp23017 import MCP23017


# ---------------------------------------------------------------------
#  1.  PIN MAP  (these are the REAL nRF52840 Feather names from the board)
# ---------------------------------------------------------------------
#  Wire each peripheral to these exact pads. All of them are broken out on
#  your board's silk. If you soldered an LED/display line to a DIFFERENT
#  pad, just change its name here to match.

# ST7789 LCD (SPI). CLK/DIN must be the hardware-SPI pins.
LCD_CLK = board.SCK          # LCD "CLK"
LCD_DIN = board.MOSI         # LCD "DIN"  (board silk "MO")
LCD_CS  = board.A0           # LCD "CS"
LCD_DC  = board.D6           # LCD "DC"
LCD_RST = board.D9           # LCD "RST"
LCD_BL  = board.A1           # LCD "BL"

# Indicator LEDs:  GPIO -> 1k -> LED anode ; cathode -> GND  (active HIGH)
LED_CAPS     = board.D10
LED_NUM      = board.D11
LED_BAT_LOW  = board.D12
LED_BAT_GOOD = board.D13

# Battery sense (internal 2:1 divider on the Feather)
try:
    BATTERY_PIN = board.VOLTAGE_MONITOR
except AttributeError:
    BATTERY_PIN = board.A6


# ---------------------------------------------------------------------
#  2.  I2C  +  the two MCP23017 expanders
# ---------------------------------------------------------------------
i2c = busio.I2C(board.SCL, board.SDA, frequency=400_000)

mcp1 = MCP23017(i2c, address=0x20)   # U1 : columns 0..15
mcp2 = MCP23017(i2c, address=0x21)   # U2 : columns 16..20 + rows 0..5

# get_pin(n): n = 0..7 -> GPA0..GPA7 ,  n = 8..15 -> GPB0..GPB7
col_pins = [
    mcp1.get_pin(0),  mcp1.get_pin(1),  mcp1.get_pin(2),  mcp1.get_pin(3),   # Col0-3   U1 GPA0-3
    mcp1.get_pin(4),  mcp1.get_pin(5),  mcp1.get_pin(6),  mcp1.get_pin(7),   # Col4-7   U1 GPA4-7
    mcp1.get_pin(8),  mcp1.get_pin(9),  mcp1.get_pin(10), mcp1.get_pin(11),  # Col8-11  U1 GPB0-3
    mcp1.get_pin(12), mcp1.get_pin(13), mcp1.get_pin(14), mcp1.get_pin(15),  # Col12-15 U1 GPB4-7
    mcp2.get_pin(0),  mcp2.get_pin(1),  mcp2.get_pin(2),  mcp2.get_pin(3),   # Col16-19 U2 GPA0-3
    mcp2.get_pin(4),                                                          # Col20    U2 GPA4
]
row_pins = [
    mcp2.get_pin(8),  mcp2.get_pin(9),  mcp2.get_pin(10),                     # Row0-2  U2 GPB0-2
    mcp2.get_pin(11), mcp2.get_pin(12), mcp2.get_pin(13),                     # Row3-5  U2 GPB3-5
]
COLS = len(col_pins)   # 21
ROWS = len(row_pins)   # 6


# ---------------------------------------------------------------------
#  3.  Keyboard + matrix scanner
# ---------------------------------------------------------------------
#  Diodes are COL2ROW. If keys don't register / everything ghosts, change
#  COL2ROW to ROW2COL and re-test.
keyboard = KMKKeyboard()
keyboard.matrix = MatrixScanner(
    cols=col_pins,
    rows=row_pins,
    diode_orientation=DiodeOrientation.COL2ROW,
)


# ---------------------------------------------------------------------
#  4.  KEYMAP  (full-size, mapped from your layout photo)
# ---------------------------------------------------------------------
#  Row-major: index = Row*21 + Col.  Columns are:
#     0..13  = main typing block        (14 wide)
#     14..16 = nav cluster (Ins/Home... / arrows)
#     17..20 = numpad
#  If a key prints wrong, only THAT row/col is mismatched to your wiring;
#  swap it here. Empty intersections are KC.NO.
_______ = KC.TRNS
XXXXXXX = KC.NO

_L0 = [
    # Row0 : Esc  F1-F12            | Print Scroll Pause | Cal Mute Vol- Vol+
    KC.ESC,  KC.F1,  KC.F2,  KC.F3,  KC.F4,  KC.F5,  KC.F6,  KC.F7,  KC.F8,  KC.F9,  KC.F10, KC.F11, KC.F12, XXXXXXX, KC.PSCR, KC.SLCK, KC.PAUS, XXXXXXX, KC.MUTE, KC.VOLD, KC.VOLU,
    #                                                          ^Col17 "Cal": set to KC.CALCULATOR if your KMK build has it
    # Row1 : ` 1-0 - = Bksp        | Ins Home PgUp     | Num  /  *  -
    KC.GRV,  KC.N1,  KC.N2,  KC.N3,  KC.N4,  KC.N5,  KC.N6,  KC.N7,  KC.N8,  KC.N9,  KC.N0,  KC.MINS, KC.EQL, KC.BSPC, KC.INS,  KC.HOME, KC.PGUP, KC.NLCK, KC.PSLS, KC.PAST, KC.PMNS,
    # Row2 : Tab Q-P [ ] \         | Del End  PgDn     | 7  8  9  +
    KC.TAB,  KC.Q,   KC.W,   KC.E,   KC.R,   KC.T,   KC.Y,   KC.U,   KC.I,   KC.O,   KC.P,   KC.LBRC, KC.RBRC, KC.BSLS, KC.DEL,  KC.END,  KC.PGDN, KC.P7,   KC.P8,   KC.P9,   KC.PPLS,
    # Row3 : Caps A-L ; ' Enter    |  (none)           | 4  5  6
    KC.CAPS, KC.A,   KC.S,   KC.D,   KC.F,   KC.G,   KC.H,   KC.J,   KC.K,   KC.L,   KC.SCLN, KC.QUOT, KC.ENT,  XXXXXXX, XXXXXXX, XXXXXXX, XXXXXXX, KC.P4,   KC.P5,   KC.P6,   XXXXXXX,
    # Row4 : LShift Z-/ RShift     |     Up            | 1  2  3  KPEnter
    KC.LSFT, KC.Z,   KC.X,   KC.C,   KC.V,   KC.B,   KC.N,   KC.M,   KC.COMM, KC.DOT, KC.SLSH, KC.RSFT, XXXXXXX, XXXXXXX, XXXXXXX, KC.UP,   XXXXXXX, KC.P1,   KC.P2,   KC.P3,   KC.PENT,
    # Row5 : Ctrl Win Alt Space Alt Fn Ctrl | Left Down Right | 0  .
    KC.LCTL, KC.LGUI, KC.LALT, XXXXXXX, XXXXXXX, KC.SPC, XXXXXXX, XXXXXXX, XXXXXXX, KC.RALT, KC.MO(1), KC.RCTL, XXXXXXX, XXXXXXX, KC.LEFT, KC.DOWN, KC.RIGHT, KC.P0, XXXXXXX, KC.PDOT, XXXXXXX,
]

# Layer 1 (Fn): transparent except the USB/BLE toggle on Fn+Esc.
_L1 = [_______] * (ROWS * COLS)
_L1[0] = KC.HID     # Fn + Esc  ->  switch USB <-> Bluetooth

keyboard.keymap = [_L0, _L1]


# ---------------------------------------------------------------------
#  5.  Modules: layers + status/animation module
# ---------------------------------------------------------------------
layers = Layers()


def _out(pin):
    d = digitalio.DigitalInOut(pin)
    d.direction = digitalio.Direction.OUTPUT
    d.value = False
    return d


class StatusModule(Module):
    """Lock LEDs from host (USB), battery LEDs from the LiPo, and an
    animated cherry-blossom scene on the LCD. All peripheral code is
    guarded so a bad pin or missing display never stops typing."""

    def __init__(self):
        self._n = 0
        self._frame = 0
        self._hid = None

        # ---- LEDs ----
        self.led_caps = self.led_num = self.led_low = self.led_good = None
        try:
            self.led_caps = _out(LED_CAPS)
            self.led_num = _out(LED_NUM)
            self.led_low = _out(LED_BAT_LOW)
            self.led_good = _out(LED_BAT_GOOD)
        except Exception as e:      # noqa: BLE001
            print("LED init failed:", e)

        # ---- battery ADC ----
        self.batt = None
        try:
            self.batt = analogio.AnalogIn(BATTERY_PIN)
        except Exception as e:      # noqa: BLE001
            print("Battery init failed:", e)

        # ---- LCD scene ----
        self._display = None
        self._petals = []
        self._px = self._py = self._pvx = self._pvy = []
        self._W = self._H = 0
        self._lbl = None
        try:
            self._setup_scene()
        except Exception as e:      # noqa: BLE001
            print("LCD init failed:", e)

    # ---------- cherry-blossom scene ----------
    def _setup_scene(self):
        import displayio
        import vectorio
        import random
        import terminalio
        from adafruit_st7789 import ST7789
        from adafruit_display_text import label
        try:
            from fourwire import FourWire            # CircuitPython 9+
        except ImportError:
            from displayio import FourWire            # CircuitPython 8

        self._rand = random
        displayio.release_displays()
        spi = board.SPI()
        bus = FourWire(spi, command=LCD_DC, chip_select=LCD_CS,
                       reset=LCD_RST, baudrate=24_000_000)
        # 1.9" 170x320 panel in landscape. If the image is shifted/rotated
        # wrong, tweak rotation (0/90/180/270) and rowstart/colstart.
        # If it's garbled, lower baudrate (e.g. 12_000_000).
        disp = ST7789(bus, width=320, height=170,
                      rowstart=35, colstart=0, rotation=90)
        W, H = 320, 170
        self._W, self._H = W, H

        bl = digitalio.DigitalInOut(LCD_BL)
        bl.direction = digitalio.Direction.OUTPUT
        bl.value = True                               # backlight on

        def pal(color):
            p = displayio.Palette(1)
            p[0] = color
            return p

        sky = pal(0xFFF0F4)      # soft pink-white sky
        wood = pal(0x6B4A2B)     # trunk brown
        pink = pal(0xFF8FB4)     # blossom
        pink2 = pal(0xFFC2D6)    # blossom highlight
        petalc = pal(0xFFB0C6)   # falling petal

        root = displayio.Group()
        root.append(vectorio.Rectangle(pixel_shader=sky, width=W, height=H, x=0, y=0))

        # trunk + two branches (stylised, bottom-left)
        root.append(vectorio.Polygon(pixel_shader=wood, x=0, y=0, points=[
            (36, H), (46, H), (52, 74), (44, 62), (40, 62), (34, 76)]))
        root.append(vectorio.Polygon(pixel_shader=wood, x=0, y=0, points=[
            (44, 94), (98, 60), (102, 66), (46, 102)]))
        root.append(vectorio.Polygon(pixel_shader=wood, x=0, y=0, points=[
            (42, 110), (8, 86), (6, 92), (42, 118)]))

        # blossom canopy
        canopy = [(44, 56, 19), (68, 44, 15), (92, 56, 14),
                  (30, 62, 13), (80, 66, 13), (54, 40, 13),
                  (18, 76, 11), (100, 62, 11)]
        for (cx, cy, r) in canopy:
            root.append(vectorio.Circle(pixel_shader=pink, radius=r, x=cx, y=cy))
        for (cx, cy, r) in canopy[:4]:
            root.append(vectorio.Circle(pixel_shader=pink2, radius=max(3, r - 7),
                                        x=cx + 3, y=cy - 3))

        # falling petals
        N = 14
        self._px, self._py, self._pvx, self._pvy = [], [], [], []
        self._petals = []
        for _ in range(N):
            x = float(random.randint(0, W - 1))
            y = float(random.randint(-H, H - 1))
            c = vectorio.Circle(pixel_shader=petalc,
                                radius=random.randint(2, 4),
                                x=int(x), y=int(y))
            root.append(c)
            self._petals.append(c)
            self._px.append(x)
            self._py.append(y)
            self._pvy.append(random.uniform(0.7, 1.9))     # fall speed
            self._pvx.append(random.uniform(-0.7, 0.7))    # sideways drift

        # tiny status readout (delete these 2 lines for a pure scene)
        self._lbl = label.Label(terminalio.FONT, text="", color=0x9A5B72,
                                x=W - 96, y=10)
        root.append(self._lbl)

        disp.root_group = root
        self._display = disp

    def _animate(self):
        r = self._rand
        for i, c in enumerate(self._petals):
            self._py[i] += self._pvy[i]
            self._px[i] += self._pvx[i]
            if self._py[i] > self._H:                 # recycle at the top
                self._py[i] = -float(r.randint(0, 30))
                self._px[i] = float(r.randint(0, self._W - 1))
            c.x = int(self._px[i]) % self._W
            c.y = int(self._py[i])

    # ---------- HID lock-LED helper ----------
    def _get_hid(self):
        try:
            import usb_hid
            for d in usb_hid.devices:
                if d.usage_page == 0x01 and d.usage == 0x06:
                    return d
        except Exception:           # noqa: BLE001
            pass
        return None

    def _battery_volts(self):
        if not self.batt:
            return None
        return (self.batt.value / 65535) * 3.3 * 2

    # ================= KMK Module hooks =================
    def during_bootup(self, keyboard):
        self._hid = self._get_hid()

    def before_matrix_scan(self, keyboard):
        return

    def after_matrix_scan(self, keyboard):
        # step the animation a bit slower than the scan loop
        self._frame += 1
        if self._display is not None and (self._frame & 1) == 0:
            try:
                self._animate()
            except Exception:       # noqa: BLE001
                pass

    def process_key(self, keyboard, key, is_pressed, int_coord):
        return key

    def before_hid_send(self, keyboard):
        return

    def after_hid_send(self, keyboard):
        self._n += 1

        # lock LEDs (host reports these over USB; BLE usually does not)
        if self.led_caps and self._hid:
            try:
                report = self._hid.get_last_received_report()
                if report:
                    leds = report[0]
                    self.led_num.value = bool(leds & 0x01)    # Num Lock
                    self.led_caps.value = bool(leds & 0x02)   # Caps Lock
            except Exception:       # noqa: BLE001
                pass

        # battery LEDs + status text, throttled
        if self._n % 1500 == 0:
            v = self._battery_volts()
            if v is not None and self.led_low and self.led_good:
                self.led_low.value = v < 3.5
                self.led_good.value = v >= 3.7
            if self._lbl is not None:
                try:
                    txt = ""
                    try:
                        txt = "BLE " if keyboard.hid_type == HIDModes.BLE else "USB "
                    except Exception:   # noqa: BLE001
                        pass
                    if v is not None:
                        txt += "{:.2f}V".format(v)
                    self._lbl.text = txt
                except Exception:       # noqa: BLE001
                    pass

    def on_powersave_enable(self, keyboard):
        for led in (self.led_caps, self.led_num, self.led_low, self.led_good):
            if led:
                led.value = False

    def on_powersave_disable(self, keyboard):
        return

    def deinit(self, keyboard):
        return


keyboard.modules = [layers, StatusModule()]


# ---------------------------------------------------------------------
#  6.  Go!
# ---------------------------------------------------------------------
#  USB-primary here = plug in and type immediately (best for first bring-up).
#  Fn+Esc (KC.HID) switches to Bluetooth at runtime.
#  For a daily WIRELESS keyboard, swap these so BLE is primary:
#       hid_type=HIDModes.BLE, secondary_hid_type=HIDModes.USB
if __name__ == "__main__":
    keyboard.go(
        hid_type=HIDModes.USB,
        secondary_hid_type=HIDModes.BLE,
        ble_name="NRF Keyboard",
    )
